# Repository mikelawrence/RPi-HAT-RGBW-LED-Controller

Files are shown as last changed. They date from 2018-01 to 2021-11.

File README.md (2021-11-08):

# Raspberry Pi RGBW LED Controller HAT
This is a [Raspberry Pi B+ HAT](https://github.com/raspberrypi/hats) that supports four high power LEDs. Each LED output uses a resistor configurable constant current driver with PWM support to control light intensity. A fourth LED channel was added to support color LEDs that have an extra Green or White LED. This HAT also supports Common-Anode LED configurations. The component selection as shown in the BOM is for a 50W RGB LED light that uses a constant current of 550mA at 24V-16.8V. The Design section discusses this in detail.

This PCB is designed using [KiCad 5.0.0](http://kicad.org). This HAT is based on [RPi_Hat_Template](https://github.com/xesscorp/RPi_Hat_Template) by XESS Corp.

_Note: The LM3414 parts have an exposed pad on the bottom which requires either a reflow oven or hot air to solder properly._

_Note: This HAT does not have the camera flex slot or the display flex cutout so technically cannot be called a HAT._

## Status
* Rev 1.0 PCB has been ordered, assembled, and tested.
  * Order the PCB from [OSH Park](https://oshpark.com/shared_projects/8nXTFx94).
  * Order the parts from Mouser using this [Shared BOM](https://www.mouser.com/ProjectManager/ProjectDetail.aspx?AccessID=8e67d22b4b).
  * The Green LED failed on one of my lights. The board is working as it should. This is most likely a LED module problem or incorrect output current. Replaced the module, changed the current from 550mA to 500mA and added a scale factor on the green output which currently limits the duty cycle to a maximum of 75%. Green output is higher in intensity anyways.

## Board Preview
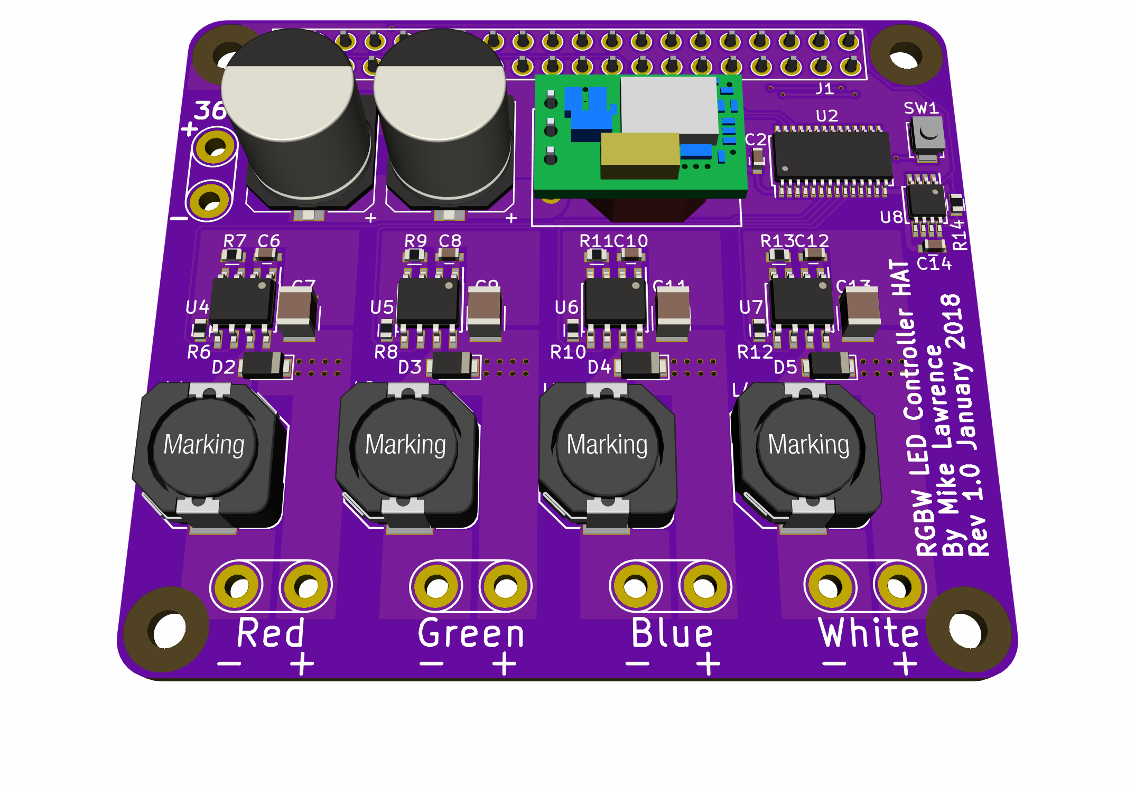
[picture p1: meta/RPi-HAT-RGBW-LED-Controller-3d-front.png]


## Design
### Input Power
Input power is 36VDC nominal with a range of 30V-37V. Input current is a maximum of 2A. This limit is due to the maximum current of the reverse input protection bridge rectifier (D1) which also serves to reduce the voltage on the 5V DC-DC converter (U3). If higher current is needed remove D1 and make the maximum input voltage 35VDC.

The Raspberry Pi can be safely back-powered by this HAT because the Ideal Diode circuit provides protection to both the Raspberry Pi and this HAT when the Raspberry Pi is powered by another source. Maximum Raspberry Pi power is 1.5A. Usually the Raspberry Pi will take substantially less than 1.5A when it is used with no external connections.

Example power budget...Powering a [50W RGB LED light](http://www.ebay.com/sch/sis.html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) purchased on eBay. The RGB LEDs of this light are wired with four wires in a common-anode configuration. For this light the White LED section is left unpopulated.

| | Current | Voltage | Power |
|---|---|---|---|
| Red | 550mA | 16.8V | 9.24W |
| Green | 550mA | 24V | 13.2W |
| Blue | 550mA | 24V | 13.2W |
| LED Power | | | 35.6W |
| LED Power @ 80% Efficiency| | | 44.6W |
| Raspberry Pi | | | 10.0W |
| Total System Power | | | 54.6W |

A 60W 36VDC power supply will drive the Raspberry Pi, RGBW LED Controller HAT, and the High Power LEDs. [This](http://www.meanwellusa.com/webapp/product/search.aspx?prod=HLG-60H) power supply (part number HLG-60) from Mean Well will drive the 50W RGB light nicely.

### Power Reality Check
In my testing I placed a Raspberry Pi, RGBW LED Controller HAT, and a 60W Power Supply in an enclosure to check temperatures. When I ran a rainbow sweep test the power consumption was around 18W and the HAT had a temperature rise of about 20C - 25C over room temperature. A static purple color test (both read and blue at full power) with power consumption around 35W the HAT temperature rise was 30C - 35C. Clearly this HAT will need better cooling to run higher power LED configurations.

### LED driver
The LM3414 from TI is a 1-A, 60-W Common Anode-Capable Constant Current Buck LED Driver. Most constant current LED drivers have a current sense resistor in the high-side path which prevents common anode connections. The LM3414 puts the current sense resistor on the low side. This leaves the high side connected directly to the 36V of the input power. The positive side of all four LED outputs are connected together on the board forcing a common-anode topology. You must not connect the low side to ground.

The LM3414 average LED current (I<sub>L</sub>) is set by the R<sub>IADJ</sub> (R7, R9, R11, R13). Set LED average current to 550mA using the equation below.

R_{IADJ}=\frac{3125}{I_{L}}=\frac{3125}{550\times10^{-3}}=5681\Omega \textup{ choose }5.76k\Omega\textup{ standard 1\% value}

Using the standard 1% resistor value the average LED current is

I_{L}=\frac{3125}{5.76\times10^{3}}=543mA}

Choose a standard switching frequency (f<sub>SW</sub>) of 500kHz using equation below. Switching frequency (f<sub>SW</sub>) is set by R<sub>FS</sub> (R6, R8, R10, R12).

R_{FS}=\frac{20\times10^9}{f_{SW}}=\frac{20\times10^9}{500\times10^3}=40k\Omega\textup{ choose }40.2k\Omega \textup{ standard 1\% value}

Using the standard 1% resistor value the switching frequency is

f_{SW}=\frac{20\times10^9}{R_{FS}}=\frac{20\times10^9}{40.2\times10^3}=498kHz

Determine minimum inductor value from maximum peak-to-peak LED current ripple (ΔI<sub>LPP</sub>) using equation below. Set ΔI<sub>LPP</sub> to 200mA.

L=\frac{(V_{IN}-V_{LED})\cdot V_{LED}}{f_{SW}\cdot V_{IN}\cdot \Delta I_{L-PP}}=\frac{(36-16.8)\cdot16.8}{498\times10^3\cdot 36\cdot 200\times10^3}=90\mu H\textup{ choose }100\mu H\textup{ standard value}

Using the standard inductor value the peak-to-peak LED current ripple is

\Delta I_{L-PP}=\frac{(V_{IN}-V_{LED})\cdot V_{LED}}{f_{SW}\cdot V_{IN}\cdot L}=\frac{(36-16.8)\cdot16.8}{498\times10^{3}\cdot 36\cdot 100\times10^{-6}}=180mA

Determine peak LED current (I<sub>LP</sub>) using selected components using equation below. I<sub>LP</sub> is also the peak current through the inductor.

I_{LP}=\frac{(V_{IN}-V_{LED})\cdot V_{LED}}{f_{SW}\cdot V_{IN}\cdot 2\cdot L}+I_{L}

I_{LP}=\frac{(36-16.8)\cdot16.8}{498\times10^{3}\cdot2\cdot 100\times10^{-6}}+543\times10^{-3}=633mA

Compute the operating duty cycle (D) using equation below.

D=\frac{V_{LED}}{V_{IN}}=\frac{16.8}{36}=0.467

Determine minimum C<sub>IN</sub> (C7, C9, C11, C13) for 200mV or less voltage ripple (ΔV<sub>IN</sub>) using equation below.

C_{IN}=\frac{D\cdot (1-D)\cdot I_{L}}{f_{SW}\cdot \Delta V_{IN}}

C_{IN}=\frac{0.467\cdot(1-0.467)\cdot 543\times10^{-3}}{498\times10^{3}\cdot200\times10^{-3}}=1.36\mu F\textup{ choose }2.2\mu F\textup{ standard value}

### PWM Controller
A Raspberry Pi has only one hardware capable PWM pin (GPIO18). With up to four PWM outputs needed for this HAT I decided to use a PCA9685 from NXP alleviate the load on the Raspberry Pi. The PCA9685 from NXP is a 16-Channel, 12-bit, I<sup>2</sup>C PWM controller. It supports independent LED on and off times so the LED outputs can be adjusted in phase along with pulse width. However, when phase is changed from 0 the next PWM cycle will reset the output. For frequent updates this causes the output light to flicker.

There are few settings that are important to using the PCA9685 on this HAT. First the EXTCLK bit in the MODE1 register must be set to 0. In the MODE2 register the INVRT bit must be set to 0 and the OUTDRV bit must be set to 1. Luckily this is the default state for all of these bits.

## Raspberry Pi Setup
This setup makes two key assumptions. First you are using Raspbian. Second, Python3 is the target programming environment. Install or update Python3 and necessary libraries by performing the following...
```
sudo apt-get update
sudo apt-get -y install build-essential python3-dev python3-pip git i2c-tools python3-w1thermsensor
pip3 install Adafruit-GPIO paho-mqtt
```

### Clone this Repository
Now is a good time to clone this repository on your Raspberry Pi. Clearly the KiCad files are not needed to configure and run this code on your Raspberry Pi so you pick and choose the files needed but these instructions will clone the entire repository.
```
mkdir ~/projects
cd ~/projects
git clone https://github.com/mikelawrence/RPi-HAT-RGBW-LED-Controller
```

### Configure ID EEPROM
Raspberry Pi HATs require an ID EEPROM with data that uniquely identifies every hat ever made. Start by cloning this repository on your Raspberry Pi, building the EEPROM tools, and make the the `eeprom_settings.eep` file.
```
cd ~/projects/RPi-HAT-RGBW-LED-Controller/eeprom/
make all
./eepmake eeprom_settings.txt eeprom_settings.eep
```
The next command writes the freshly generated and unique `eeprom_settings.eep` file to the EEPROM but you must push and hold the write switch on the HAT before executing this command. By default the EEPROM on the HAT is write protected. Pushing the write switch allows writes to occur.
```
sudo ./eepflash.sh -w -f=eeprom_settings.eep -t=24c32
```
You will see the following if writing to the EEPROM was successful.
```
This will attempt to talk to an eeprom at i2c address 0x50. Make sure there is an eeprom at this address.
This script comes with ABSOLUTELY no warranty. Continue only if you know what you are doing.
Do you wish to continue? (yes/no): yes
Writing...
0+1 records in
0+1 records out
117 bytes (117 B) copied, 2.31931 s, 0.1 kB/s
Done.
```
This is what you will see if there is a problem communicating with the EEPROM.
```
This will attempt to talk to an eeprom at i2c address 0x50. Make sure there is an eeprom at this address.
This script comes with ABSOLUTELY no warranty. Continue only if you know what you are doing.
Do you wish to continue? (yes/no): yes
Writing...
dd: error writing ‘/sys/class/i2c-adapter/i2c-3/3-0050/eeprom’: Connection timed out
0+1 records in
0+0 records out
0 bytes (0 B) copied, 0.0539977 s, 0.0 kB/s
Error doing I/O operation.
```

### Setup Interfaces
For this HAT you will need to enable the I<sup>2</sup>C and 1-Wire interfaces. From the command line type `sudo raspi-config ` and follow the prompts to install I<sup>2</sup>C support in the kernel.

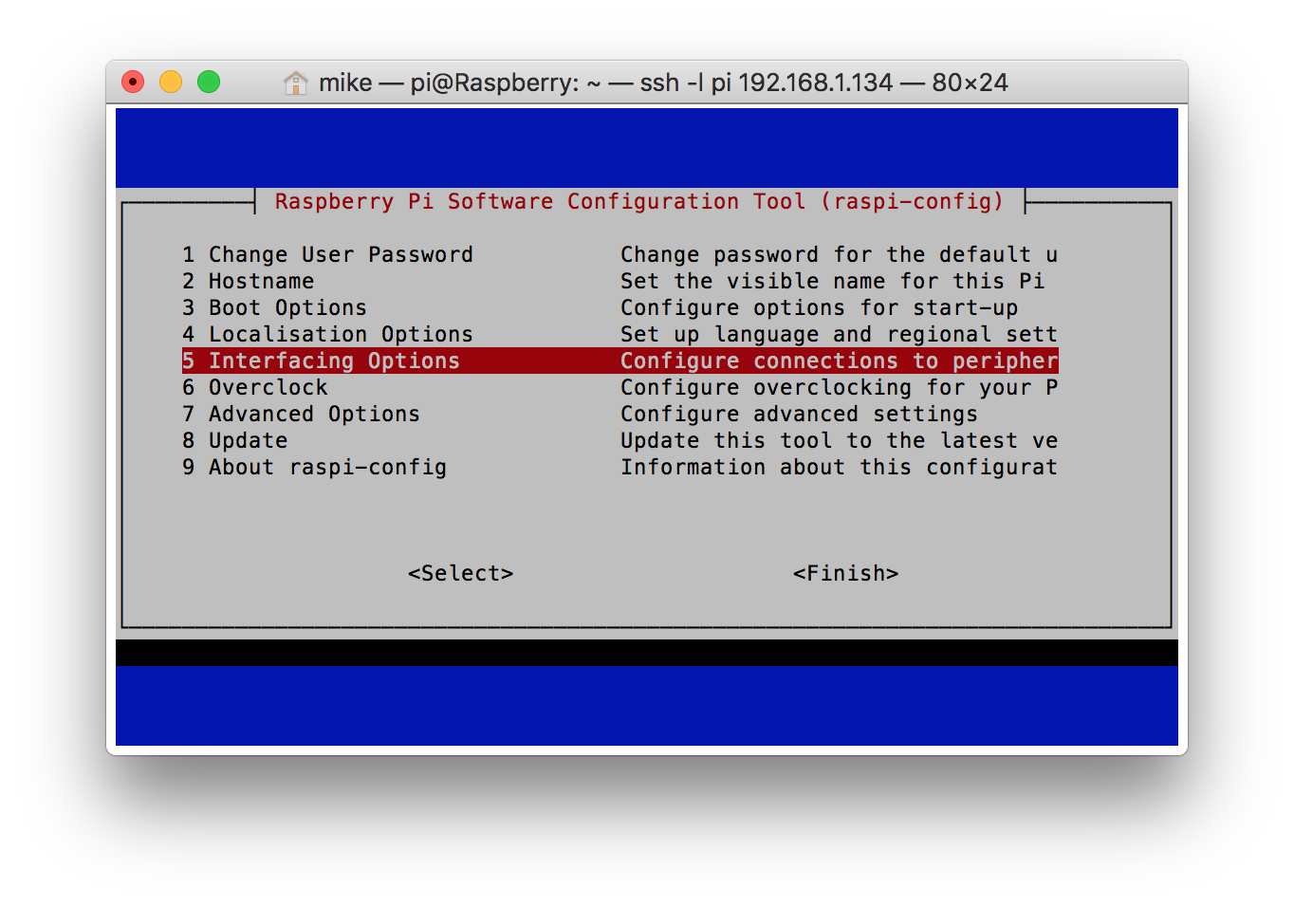
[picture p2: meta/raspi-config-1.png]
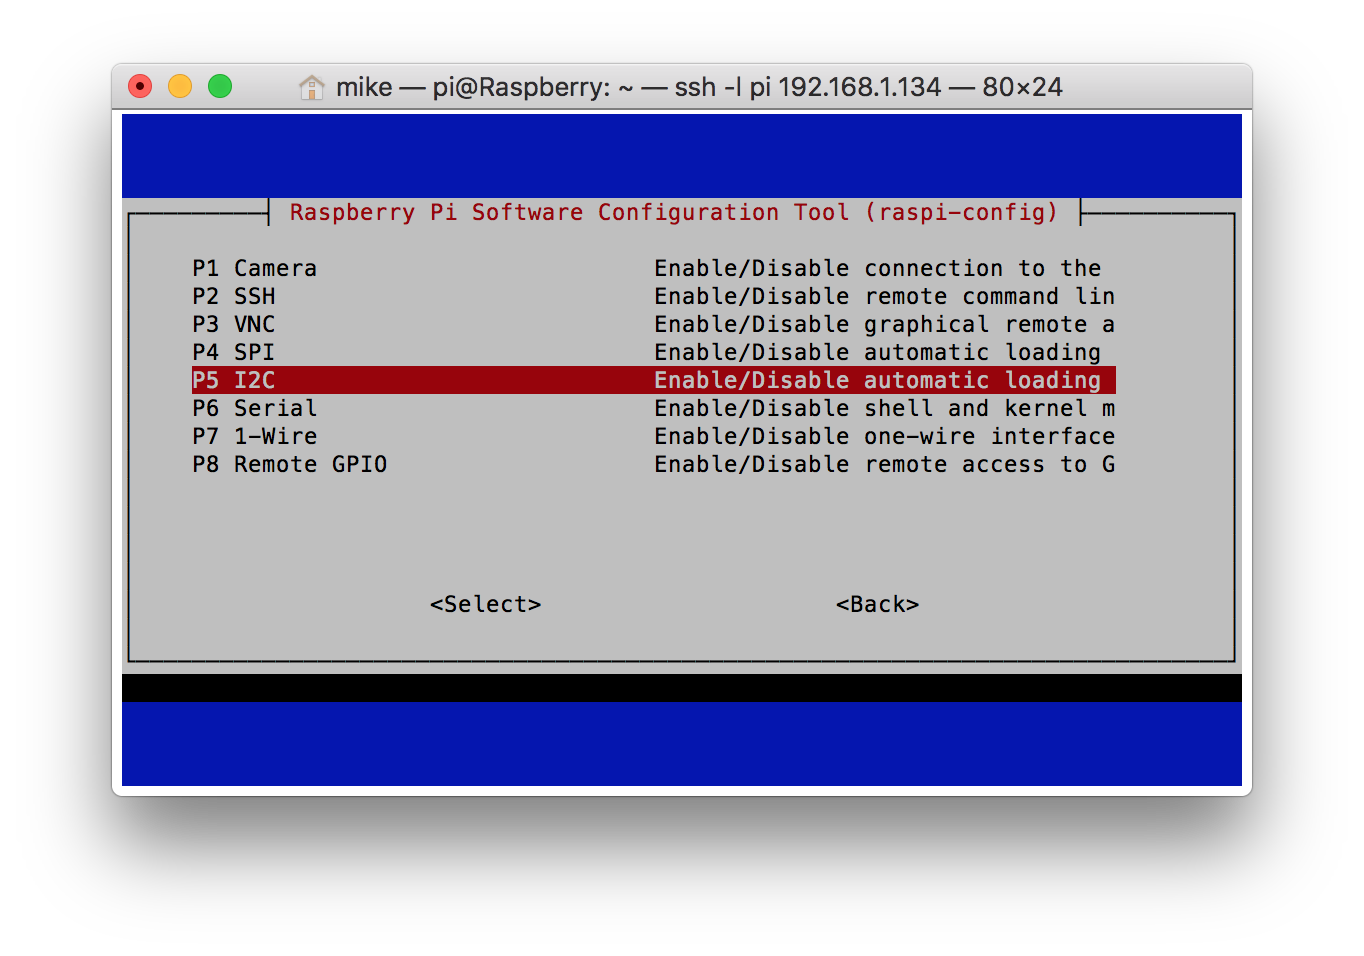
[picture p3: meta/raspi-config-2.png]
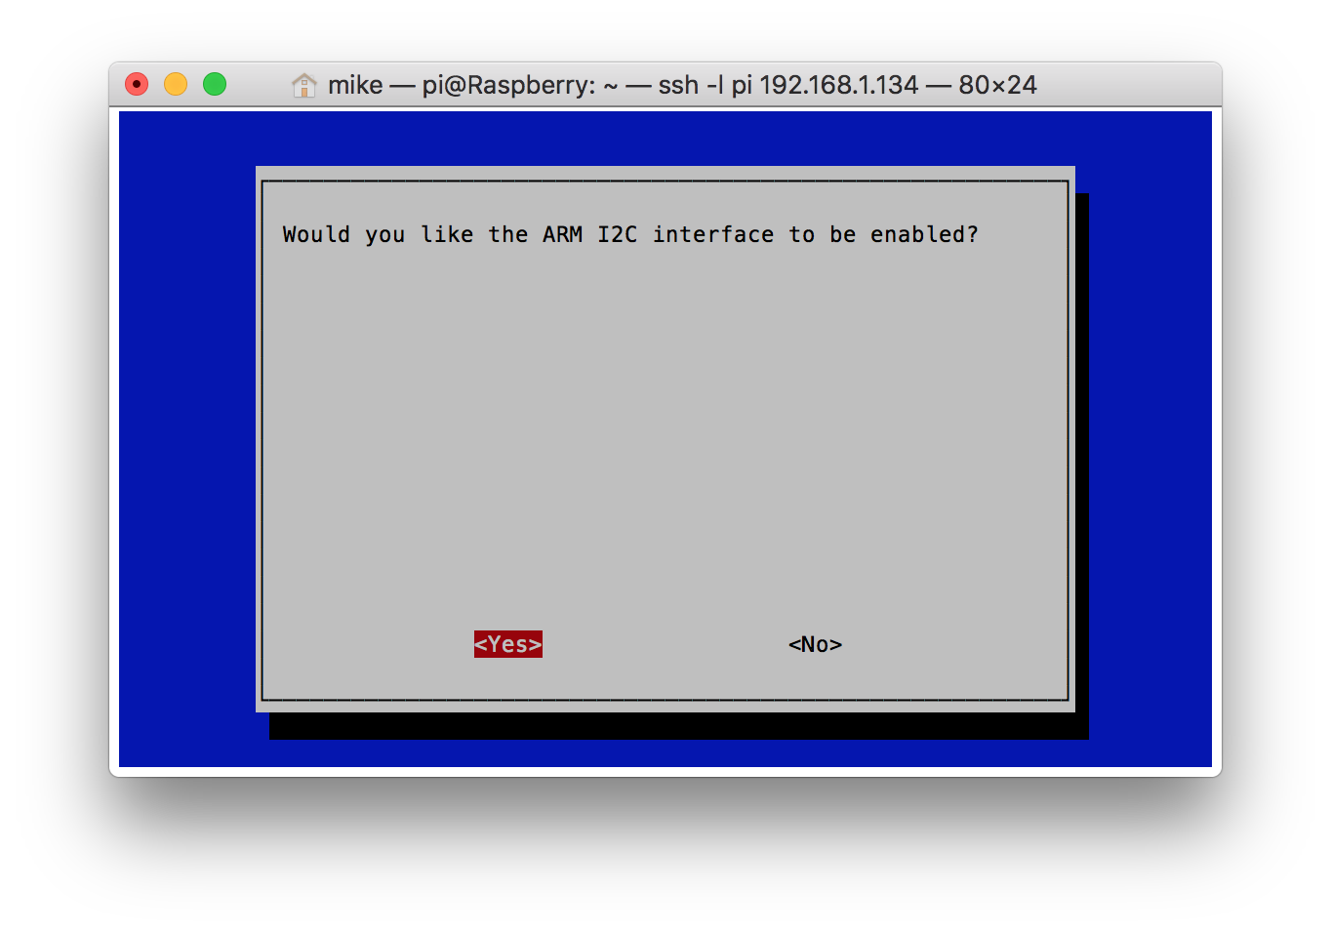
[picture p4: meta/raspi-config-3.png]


Now follow the same actions but enabling the 1-Wire interface.

It's time to reboot your Raspberry Pi with `sudo reboot`.

### Test PCA9685 12-bit PWM Controller
Now let's see if the PWM Controller is present on the I<sup>2</sup>C bus by running `sudo i2cdetect -y 1`. Looking at the output of the `i2cdetect` command you will see `40` and `70` in a field of `--` when the PCA9685 is detected on the bus. If you don't see the `40` something is wrong with the HAT or the bus is disabled. `i2cdetect` was installed when you installed the i2c-tools package in the Raspberry Pi Setup section.
```
pi@rpi-rgb-led-1:~ $ sudo i2cdetect -y 1
     0  1  2  3  4  5  6  7  8  9  a  b  c  d  e  f
00:          -- -- -- -- -- -- -- -- -- -- -- -- --
10: -- -- -- -- -- -- -- -- -- -- -- -- -- -- -- --
20: -- -- -- -- -- -- -- -- -- -- -- -- -- -- -- --
30: -- -- -- -- -- -- -- -- -- -- -- -- -- -- -- --
40: 40 -- -- -- -- -- -- -- -- -- -- -- -- -- -- --
50: -- -- -- -- -- -- -- -- -- -- -- -- -- -- -- --
60: -- -- -- -- -- -- -- -- -- -- -- -- -- -- -- --
70: 70 -- -- -- -- -- -- --                         
```

### Test the DS18B20 1-Wire Thermometer
[Python3-w1thermsensor](https://github.com/timofurrer/w1thermsensor) is a nice 1-Wire python library that also supports command line reading of temperatures from 1-Wire devices. You should have already installed this package in the [Raspberry Pi Setup](#Raspberry-Pi-Setup) section.

Now test the RGBW LED Controller HAT's DS18B20 temperature sensor using `w1thermsensor all`.
```
pi@rpi-rgb-led-1:~ $ w1thermsensor all
Got temperatures of 1 sensors:
  Sensor 1 (00000991f822) measured temperature: 25.69 celsius
```
# RGBW LED Controller HAT Test
See code-test section [README.md](code-test/README.md) for code that fires up the RGBW LED Controller HAT by blending between the primary colors and monitoring temperatures.

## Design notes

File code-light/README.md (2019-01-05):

# RGB Floodlight Application
The RGB Floodlight application is written in Python 3 and supports the RGB hardware elements of the RGBW LED Controller HAT which in turn drives a 50W RGB Floodlight. The application is also a discoverable light for [Home Assistant](https://home-assistant.io/), an open-source home automation platform running on Python 3. [MQTT](http://mqtt.org/), a machine-to-machine (M2M)/"Internet of Things" connectivity protocol, is the basis of communication with Home Assistant.

All settings for this application are in the '[rgbfloodlight.conf](rgbfloodlight.conf)'. This is where you point to the correct MQTT broker and configure how the light works. There are a few settings of note here. Discovery_Enabled = false will prevent Home Assistant from automatically discovering the light. Group_Enable = true adds a second MQTT light to Home Assistant that supports multiple RGB Floodlights. Each light that has the same Group_ID will respond state changes in unison. Be sure to set Group_Master = true for only one light in a group.

If you don't want to use discovery here is the configuration of the light in Home Assistant. Note the 'Studio-Roof-Floodlight' you see in the example yaml is the Node_ID which is specified in the 'rgbfloodlight.conf' file. The light platform for Home Assistant is [MQTT JSON Light](https://www.home-assistant.io/components/light.mqtt//) configured with RGB and brightness support. The RGB Floodlight also reports internal temperature (platform [MQTT Sensor](https://home-assistant.io/components/sensor.mqtt/)) and an over temperature alarm (platform [MQTT Binary_Sensor](https://home-assistant.io/components/binary_sensor.mqtt/))
```yaml
# Example configuration.yaml entry
light:
  # Main RGB Light config
  - platform: mqtt_json
    name: Studio Roof Light
    state_topic: "hass/light/studio_roof_light/rgblight/state"
    command_topic: "hass/light/studio_roof_light/rgblight/set"
    brightness: true
    rgb: true
    effect: true
    qos: 1
    retain: true
    brightness_scale: 255
    effect_list:
      - Single Color
      - Single Color Bounce
      - Primary Bounce
      - Primary Blend
      - Rainbow Bounce
      - Rainbow Blend
      - Christmas
      - Halloween
# Include the next three settings if you want availability in Home Assistant
# Availability seems marginal in Home Assistant and frequently disables
# light controls even when the light is operational.
    availability_topic: "hass/light/studio_roof_light/rgblight/status"
    payload_available: "online"
    payload_not_available: "offline"

  # Group RGB Lights config
  - platform: mqtt_json
    name: Roof Lights
    state_topic: "hass/light/roof_lights/rgblight/state"
    command_topic: "hass/light/roof_lights/rgblight/set"
    brightness: true
    rgb: true
    effect: true
    qos: 1
    retain: true
    brightness_scale: 255
    effect_list:
      - Single Color
      - Single Color Bounce
      - Primary Bounce
      - Primary Blend
      - Rainbow Bounce
      - Rainbow Blend
      - Christmas
      - Halloween

sensor:
  - platform: mqtt
    name: Studio Roof Light RSSI
    state_topic: "hass/sensor/studio_roof_light/rssi/state"
    unit_of_measurement: "dBm"
  - platform: mqtt
    name: Studio Roof Light Temperature
    state_topic: "hass/sensor/studio_roof_light/temperature/state"
    unit_of_measurement: "°C"

binary_sensor:
  - platform: mqtt
    name: Studio Roof Light Over Temperature Alarm
    state_topic: "hass/binary_sensor/studio_roof_light/hat_temperature/state"
    device_class: "heat"
    payload_on: "ON"
    payload_off: "OFF"
```
The RGB Light subscribes to the command_topic and expects JSON control data in the following format...

```JSON
{
  "brightness": 255,
  "color": {
    "r": 255,
    "g": 255,
    "b": 255
  },
  "effect": "Single Color",
  "state": "ON",
  "transition": 120
}
```
Note the "transition" parameter specifies how long a given effect last before repeating and is not part of the Home Assistant light control so an additional control and automation is required see below..
```yaml
# Input slider for transition time
input_number:
  studio_roof_light_transition_time:
    name: "Studio Roof Light Transition Speed"
    initial: 120
    min: 1
    max: 180
    step: 1

# automation to pipe the transition value over to light
automation:
  - id: studio_roof_light_transition_speed
    alias: "Studio Roof Light Transition Speed"
    initial_state: True
    hide_entity: False
    trigger:
      - platform: state
        entity_id: input_number.studio_roof_light_transition_time
    action:
      - service: mqtt.publish
        data_template:
          topic: "hass/light/studio_roof_light/rgblight/set"
          payload: '{"transition": {{ trigger.to_state.state | int }}}'

```
## Other Software Notes
The PCA9685 driver is based on Adafruit's Python PCA9685 library (PCA9685.py). While this library works it had some problems. First every register write is a single 8-bit I<sup>2</sup>C transaction even for those registers like LEDn_ON which are actually two 8-bit registers together. So I changed all multi-register writes to support the writeList() method which writes multiple bytes from a starting address in a single transaction. This required also setting the AI bit in the MODE1 register which configures the PCA9685 to auto-increment the address counter on I<sup>2</sup>C transactions. Finally I added a method, set_multiple_pwm(), that writes the LED On and LED Off values for multiple PWM channels starting with CH0. This allows the RGB PWM values to be updated simultaneously.

The rgbled.py file provides all of the RGB LED control through the PCA9685 PWM controller. Once initialized use the set() method to change color and brightness which in turn will compute appropriate PWM values and send them to the PCA9685.

The Color class is defined in the color.py file. Color is defined as a tuple representing a color using Red, Green, and Blue values with a range of [0:255]. This class defines the blend() method used to linearly blend from one color to the next. Gamma correction is provided by the gamma() method.

The colorwheel.py file is a set of classes that provide a convenient method of converting an angle with the range [0:360] to a color that is either a blend between multiple colors or a bounce effect of fading out one color before switching to another. Multiple colorwheel classes are defined as effects. For instance there is the PrimaryBlendWheel which blends between the primary colors. Or the RainbowBounceWheel which fades between colors of the Rainbow.

## Raspberry Pi Setup
This setup makes two key assumptions. First you are using Raspbian. Second, Python 3 is the target programming environment. It is assumed that you already installed the required tools and libraries as shown in the main project [README file](../README.md) but here are the commands to install or update Python 3 and necessary libraries...
```
sudo apt-get update
sudo apt-get -y install build-essential python3-dev python3-pip git i2c-tools python3-w1thermsensor
pip3 install Adafruit-GPIO paho-mqtt
```
It is also assumed that you already cloned this repository as shown in the Clone This Repository section of the main project [README file](../README.md). Be sure to edit the 'rgbfloodlight.conf' file to support your configuration. Test the software by executing the following commands.
```
cd ~/projects/RPi-HAT-RGBW-LED-Controller/code-light/
chmod 755 rgbfloodlight.py
./rgbfloodlight.py
```
If you see no errors you should be able to see your light in Home Assistant. Configuring Home Assistant is a bit of a stretch for this guide but here are a couple of hints.

* "RGB Floodlight: Failed to load state file 'rgbfloodlightstate.json'." means there is no previous state for the light. This is perfectly normal when the code is run for the first time.
* Make sure you have MQTT installed. If you use HASS.IO goto the HASS.IO configuration and install the Mosquitto Broker.
* Make sure you have MQTT discovery enabled. See [MQTT Discovery](https://home-assistant.io/docs/mqtt/discovery/).
* Make sure your MQTT discovery prefix matches the Discovery_Prefix in your RGB Floodlight configuration file.

I use HASS.IO with the Mosquitto Broker add-on installed and my configuration for MQTT is as follows...
```yaml
mqtt:
  broker: core-mosquitto
  discovery: true
  discovery_prefix: hass

```
## Systemd run at boot
To make this code run at boot enter the following commands...
```
cd ~/projects/RPi-HAT-RGBW-LED-Controller/code-light
sudo cp rgbfloodlight.service /lib/systemd/system
sudo systemctl enable rgbfloodlight.service
sudo systemctl start rgbfloodlight.service
```

# Acknowledgments
The following python libraries are required.
* [Eclipse Paho™ MQTT Python Client](https://github.com/eclipse/paho.mqtt.python)
* [Python3 w1thermsensor](https://github.com/timofurrer/w1thermsensor)
* [Adafruit Python GPIO](https://github.com/adafruit/Adafruit_Python_GPIO)

The following library is used but was modified so included in this repository.
* [Adafruit Python PCA9685](https://github.com/adafruit/Adafruit_Python_PCA9685).

The following code was pulled from the Internet
* [kbhit.py](http://home.wlu.edu/~levys/software/kbhit.py) from Simon D. Levy
* [timer.py](https://github.com/jalmeroth/homie-python/blob/master/homie/timer.py)

I want to thank Jan Almeroth for [homie-python](https://github.com/jalmeroth/homie-python/blob/master/homie/timer.py) which is a Python implementation of the Homie MQTT convention. While I ended up not using Homie it showed me how to use the Paho MQTT Python Client.

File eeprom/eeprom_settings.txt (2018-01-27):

########################################################################
# EEPROM settings text file
#
# This text file has been modifed for the Raspberry Pi Thermocouple Hat.
#
# Edit this file for your particular board and run through eepmake tool,
# then use eepflash tool to write to attached HAT ID EEPROM
#
# Tools available:
#  eepmake   Parses EEPROM text file and creates binary .eep file
#  eepdump   Dumps a binary .eep file as human readable text (for debug)
#  eepflash  Write or read .eep binary image to/from HAT EEPROM
#
########################################################################

########################################################################
# Vendor info

# 128 bit UUID. If left at zero eepmake tool will auto-generate
# RFC 4122 compliant UUID
product_uuid 00000000-0000-0000-0000-000000000000

# 16 bit product id
product_id 0x0003

# 16 bit product version
product_ver 0x0000

# ASCII vendor string  (max 255 characters)
vendor "Mike Lawrence"

# ASCII product string (max 255 characters)
product "RGBW LED Controller Hat"

########################################################################
# GPIO bank settings, set to nonzero to change from the default.
# NOTE these setting can only be set per BANK, uncommenting any of
# these will force the bank to use the custom setting.

# drive strength, 0=default, 1-8=2,4,6,8,10,12,14,16mA, 9-15=reserved
gpio_drive 0

# 0=default, 1=slew rate limiting, 2=no slew limiting, 3=reserved
gpio_slew 0

# 0=default, 1=hysteresis disabled, 2=hysteresis enabled, 3=reserved
gpio_hysteresis 0

# If board back-powers Pi via 5V GPIO header pins:
# 0 = board does not back-power
# 1 = board back-powers and can supply the Pi with a minimum of 1.3A
# 2 = board back-powers and can supply the Pi with a minimum of 2A
# 3 = reserved
# If back_power=2 then USB high current mode will be automatically
# enabled on the Pi
back_power 1

########################################################################
# GPIO pins, uncomment for GPIOs used on board
# Options for FUNCTION: INPUT, OUTPUT, ALT0-ALT5
# Options for PULL: DEFAULT, UP, DOWN, NONE
# NB GPIO0 and GPIO1 are reserved for ID EEPROM so cannot be set

#         GPIO  FUNCTION  PULL
#         ----  --------  ----
setgpio   2     ALT0      DEFAULT    # I2C
setgpio   3     ALT0      DEFAULT    # I2C
#setgpio  4     INPUT     DEFAULT
#setgpio  5     OUTPUT    DOWN
#setgpio  6     INPUT     DEFAULT
#setgpio  7     INPUT     DEFAULT
#setgpio  8     INPUT     DEFAULT
#setgpio  9     INPUT     DEFAULT
#setgpio  10    INPUT     DEFAULT
#setgpio  11    INPUT     DEFAULT
#setgpio  12    INPUT     DEFAULT
#setgpio  13    INPUT     DEFAULT
#setgpio  14    INPUT     DEFAULT
#setgpio  15    INPUT     DEFAULT
#setgpio  16    INPUT     DEFAULT
#setgpio  17    INPUT     DEFAULT
#setgpio  18    INPUT     DEFAULT
#setgpio  19    INPUT     DEFAULT
#setgpio  20    INPUT     DEFAULT
#setgpio  21    INPUT     DEFAULT
#setgpio  22    INPUT     DEFAULT
#setgpio  23    INPUT     DEFAULT
#setgpio  24    INPUT     DEFAULT
#setgpio  25    INPUT     DEFAULT
#setgpio  26    INPUT     DEFAULT
#setgpio  27    INPUT     DEFAULT

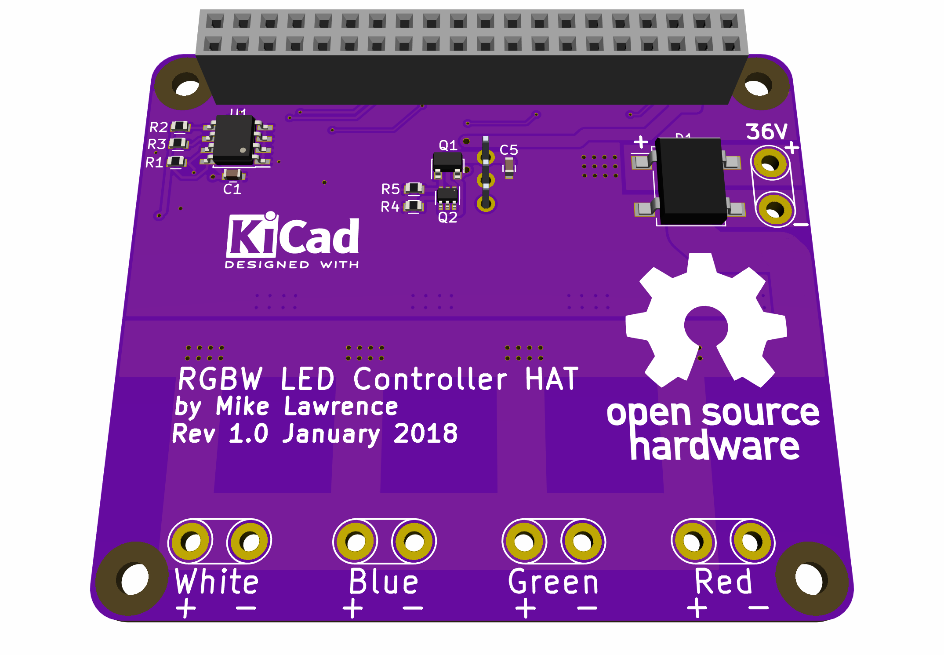
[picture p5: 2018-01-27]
meta/RPi-HAT-RGBW-LED-Controller-3d-back.png

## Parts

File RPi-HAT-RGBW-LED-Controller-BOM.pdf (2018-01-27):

# RPi RGBW LED Controller HAT Rev 1.0

Reference | Quantity | Value | Part Number | Manufacturer | Vendor | Vendor Part Number | Tolerance | Voltage
C1 C2 C14 | 3 | 0.1uF | GCJ188R71E104KA2D | Murata | Mouser | 81-GCJ188R71E104KA2D | 10% | 25V
C3 C4 | 2 | 330uF | EEE-FT1H331GP | Panasonic | Mouser | 667-EEE-FT1H331GP | 20% | 50V
C5 C6 C8 C10 C12 | 5 | 1uF | GCJ188R71E105KA01D | Murata | Mouser | 81-GCJ188R71E105KA1D | 10% | 25V
C7 C9 C11 C13 | 4 | 2.2uF | GCJ32DR72A225KA01L | Murata | Mouser | 81-GCJ32DR72A225KA1L | 10% | 100V
D1 | 1 | | DF206ST-G | Comchip Tech | Mouser | 750-DF206ST-G
D2 D3 D4 D5 | 4 | | DFLS2100-7 | Diodes Inc | Mouser | 621-DFLS2100-7
J1 | 1 | | 2222 | Adafruit | Mouser | 485-2222
L1 L2 L3 L4 | 4 | 100uH | 7447714101 | Wurth | Mouser | 710-7447714101
Q1 | 1 | | DMG2305UX-7 | Diodes Inc | Mouser | 621-DMG2305UX-7
Q2 | 1 | | BCM857BS-7-F | Diodes Inc | Mouser | 621-BCM857BS-7-F
R1 | 1 | 1k | ERJ-3EKF1001V | Panasonic | Mouser | 667-ERJ-3EKF1001V | 1%
R14 | 1 | 4.7k | ERJ-3EKF4701V | Panasonic | Mouser | 667-ERJ-3EKF4701V | 1%
R2 R3 | 2 | 3.9k | ERJ-3EKF3901V | Panasonic | Mouser | 667-ERJ-3EKF3901V | 1%
R4 | 1 | 10k | ERJ-3EKF1002V | Panasonic | Mouser | 667-ERJ-3EKF1002V | 1%
R5 | 1 | 47k | ERJ-3EKF4702V | Panasonic | Mouser | 667-ERJ-3EKF4702V | 1%
R6 R8 R10 R12 | 4 | 40.2k | ERJ-3EKF4022V | Panasonic | Mouser | 667-ERJ-3EKF4022V | 1%
R7 R9 R11 R13 | 4 | 5.76k | ERJ-3EKF5761V | Panasonic | Mouser | 667-ERJ-3EKF5761V | 1%
SW1 | 1 | | B3U-1000P | Omron | Mouser | 653-B3U-1000P
U1 | 1 | | AT24CS32-SSHM | Atmel | Mouser | 556-AT24CS32-SSHM-T
U2 | 1 | | PCA9685PW | NXP | Mouser | 771-PCA9685PW,112
U3 | 1 | | OKI-78SR-5/1.5-W36H-C | Murata | Mouser | 580-OKI78SR51.5W36HC
U4 U5 U6 U7 | 4 | | LM3414MRX/NOPB | TI | Mouser | 926-LM3414MRX/NOPB
U8 | 1 | | DS18B20U+ | Maxim | Mouser | 700-DS18B20U

1

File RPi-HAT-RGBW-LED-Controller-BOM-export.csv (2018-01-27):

Reference | Quantity | Value | Footprint | Datasheet | Part Number | Manufacturer | Vendor | Vendor Part Number | Tolerance | Voltage
C1 C14 C2 | 3 | 0.1uF | Capacitors_SMD:C_0603 |  | GCJ188R71E104KA2D | Murata | Mouser | 81-GCJ188R71E104KA2D | 10% | 25V
C3 C4 | 2 | 330uF | Capacitors_SMD:CP_Elec_10x10.5 |  | EEE-FT1H331GP | Panasonic | Mouser | 667-EEE-FT1H331GP | 20% | 50V
C10 C12 C5 C6 C8 | 5 | 1uF | Capacitors_SMD:C_0603 |  | GCJ188R71E105KA01D | Murata | Mouser | 81-GCJ188R71E105KA1D | 10% | 25V
C11 C13 C7 C9 | 4 | 2.2uF | Capacitors_SMD:C_1210 |  | GCJ32DR72A225KA01L | Murata | Mouser | 81-GCJ32DR72A225KA1L | 10% | 100V
D1 | 1 | D_Bridge_+-AA | Diodes_SMD:Diode_Bridge_DFS | https://www.mouser.com/ds/2/80/DF2005S-G%20Thru340567.%20DF210S-G%20RevF-535444.pdf | DF206ST-G | Comchip Tech | Mouser | 750-DF206ST-G
D2 D3 D4 D5 | 4 | DFLS2100 | Diodes_SMD:D_PowerDI-123 | https://www.diodes.com/assets/Datasheets/ds31475.pdf | DFLS2100-7 | Diodes Inc | Mouser | 621-DFLS2100-7
J1 | 1 | RPi_GPIO | raspberry-ml:Pin_Header_Straight_2x20 |  | 2222 | Adafruit | Mouser | 485-2222
J2 J3 J4 J5 J6 | 5 | Conn_01x02_Female | holes-ml:TH_16ga_2pos
L1 L2 L3 L4 | 4 | 100uH | inductors-ml:WE-PD-1050 |  | 7447714101 | Wurth | Mouser | 710-7447714101
Q1 | 1 | DMG2305UX | TO_SOT_Packages_SMD:SOT-23 | https://www.diodes.com/assets/Datasheets/DMG2305UX.pdf | DMG2305UX-7 | Diodes Inc | Mouser | 621-DMG2305UX-7
Q2 | 1 | BCM857BS | TO_SOT_Packages_SMD:SOT-363_SC-70-6 | https://www.diodes.com/assets/Datasheets/BCM857BS.pdf | BCM857BS-7-F | Diodes Inc | Mouser | 621-BCM857BS-7-F
R1 | 1 | 1k | Resistors_SMD:R_0603 |  | ERJ-3EKF1001V | Panasonic | Mouser | 667-ERJ-3EKF1001V | 1%
R14 | 1 | 4.7k | Resistors_SMD:R_0603 |  | ERJ-3EKF4701V | Panasonic | Mouser | 667-ERJ-3EKF4701V | 1%
R2 R3 | 2 | 3.9k | Resistors_SMD:R_0603 |  | ERJ-3EKF3901V | Panasonic | Mouser | 667-ERJ-3EKF3901V | 1%
R4 | 1 | 10k | Resistors_SMD:R_0603 |  | ERJ-3EKF1002V | Panasonic | Mouser | 667-ERJ-3EKF1002V | 1%
R5 | 1 | 47k | Resistors_SMD:R_0603 |  | ERJ-3EKF4702V | Panasonic | Mouser | 667-ERJ-3EKF4702V | 1%
R10 R12 R6 R8 | 4 | 40.2k | Resistors_SMD:R_0603 |  | ERJ-3EKF4022V | Panasonic | Mouser | 667-ERJ-3EKF4022V | 1%
R11 R13 R7 R9 | 4 | 5.76k | Resistors_SMD:R_0603 |  | ERJ-3EKF5761V | Panasonic | Mouser | 667-ERJ-3EKF5761V | 1%
SW1 | 1 | Write | Buttons_Switches_SMD:SW_SPST_B3U-1000P | http://www.mouser.com/ds/2/307/en-b3u-3615.pdf | B3U-1000P | Omron | Mouser | 653-B3U-1000P
U1 | 1 | AT24CS32 | Housings_SOIC:SOIC-8_3.9x4.9mm_Pitch1.27mm | http://www.atmel.com/images/Atmel-8869-SEEPROM-AT24CS32-Datasheet.pdf | AT24CS32-SSHM | Atmel | Mouser | 556-AT24CS32-SSHM-T
U2 | 1 | PCA9685 | Housings_SSOP:TSSOP-28_4.4x9.7mm_Pitch0.65mm |  | PCA9685PW | NXP | Mouser | 771-PCA9685PW,112
U3 | 1 | OKI-78SR-5 | murata-ml:78SR-H |  | OKI-78SR-5/1.5-W36H-C | Murata | Mouser | 580-OKI78SR51.5W36HC
U4 U5 U6 U7 | 4 | LM3414 | Housings_SOIC:TI_SO-PowerPAD-8_ThermalVias |  | LM3414MRX/NOPB | TI | Mouser | 926-LM3414MRX/NOPB
U8 | 1 | DS18B20U | Housings_SSOP:MSOP-8_3x3mm_Pitch0.65mm | https://datasheets.maximintegrated.com/en/ds/DS18B20.pdf | DS18B20U+ | Maxim | Mouser | 700-DS18B20U

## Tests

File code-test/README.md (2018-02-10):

# RGBW LED Controller HAT Test Software
The test software is written in Python 3 and supports all hardware elements on the RGBW LED Controller HAT.

The PCA9685 driver is based on Adafruit's Python PCA9685 library (PCA9685.py). While this library works it had some problems. First every register write is a single 8-bit I<sup>2</sup>C transaction even for those registers like LEDn_ON which are actually two 8-bit registers together. So I changed all multi-register writes to support the writeList function which writes multiple bytes from a starting address in a single transaction. This required also setting the AI bit in the MODE1 register which configures the PCA9685 to auto-increment the address counter. Finally I added a function that writes the LED On and LED Off values for multiple PWM channels starting with CH0. This allows the RGB PWM values to be updated simultaneously.

The rgbled.py file provides most of the color processing and RGB LED control through the PCA9685 PWM controller. Color is defined as a tuple representing a color using Red, Green, and Blue values with a range of [0:255]. The LinearWheel and SineWheel classes provide a convenient HSV to RGB color converter that takes a Hue angle with the range [0:360] and converts it to a color. The Linear Wheel uses a linear translation of colors while the SineWheel uses a Sine wave translation of colors. This [website](http://www.instructables.com/id/How-to-Make-Proper-Rainbow-and-Random-Colors-With-/) has a good explanation of the difference between linear and sinusoid hue translations.

## Example
Running test.py will start rotating through the colors of the rainbow and periodically checking the CPU and HAT temperatures.

First make sure make the python file is executable by executing the following commands.
```
cd ~/projects/RPi-HAT-RGBW-LED-Controller/code-test
chmod 755 test.py
./test.py
```
You should see something similar to the output below and more interesting your LED light should cycling through the colors of the rainbow.
```
pi@rpi-rgb-led-1:~/projects/RPi-HAT-RGBW-LED-Controller/code-test $
RPi RGBW LED Controller HAT Test
Found 1-Wire temp sensor 00000991f822

Press any key to exit.
CPU Temp = 47.2C, HAT Temp 35.4C
CPU Temp = 47.2C, HAT Temp 35.6C
CPU Temp = 47.2C, HAT Temp 35.7C
CPU Temp = 47.2C, HAT Temp 35.8C
CPU Temp = 47.8C, HAT Temp 35.9C
```

# Acknowledgments
The following python libraries were used to demonstrate the functionality of the Raspberry Pi RGBW LED Controller HAT.
* [Python3 w1thermsensor](https://github.com/timofurrer/w1thermsensor)
* [Adafruit Python GPIO](https://github.com/adafruit/Adafruit_Python_GPIO)

The following libraries were used but had to be modified.
* [Adafruit Python PCA9685](https://github.com/adafruit/Adafruit_Python_PCA9685).

The following code was pulled from the Internet
* [kbhit.py](http://home.wlu.edu/~levys/software/kbhit.py) from Simon D. Levy
* [timer.py](https://stackoverflow.com/questions/12435211/python-threading-timer-repeat-function-every-n-seconds)

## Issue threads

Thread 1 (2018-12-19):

LM3414 Symbol

blasslett, 2018-12-19:
I noticed your LM3414 symbol pins do not match what is on the datasheet.  I'm new to kicad and wanted to make sure I wasn't missing something when creating my symbol since I'm using your design as a reference.

[http://www.ti.com/ds_dgm/images/alt_snvs678f.gif](url)

mikelawrence, 2018-12-19:
My symbol pin names and numbers match what is in the datasheet but the pin locations on the schematic symbol do not match the schematic symbol you presented. I swapped pin 3 and 6 on the symbol to make my schematic less confusing. Specifically I didn't like the PWM input on the right side of this symbol. Changes like this are a matter of personal preference. Just so you know this design has been built and is in use.

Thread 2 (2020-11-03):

Not able to open in Kicad, error loading board file "(" in input/source, it also states line 6, offset 1

stefanm666, 2020-11-03:
Not able to open in Kicad, error loading board file "(" in input/source, it also states line 6, offset 1.

I wanted to modify this to suit the HV version of the LM3414, remove the power source for the PCA9685 and Rpi to run higher input voltage and make it 8 channels.

Closed 2020-11-03.

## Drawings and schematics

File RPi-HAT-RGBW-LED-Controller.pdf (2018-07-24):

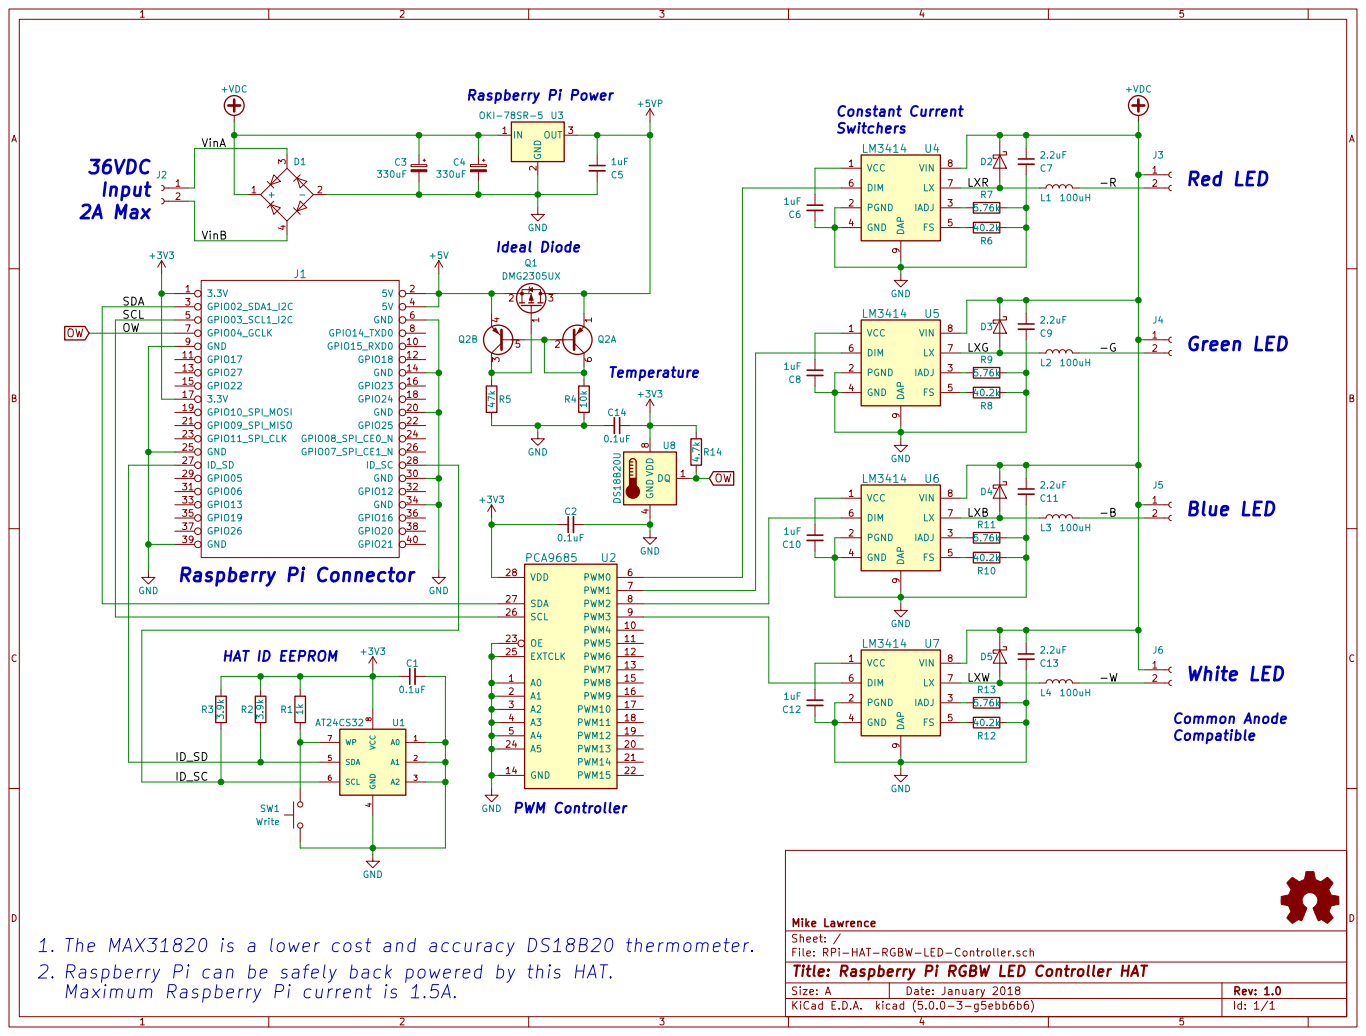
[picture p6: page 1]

Raspberry Pi Power GND

SW1 Write HAT ID EEPROM

4 SDA 5 SCL 6 WP 7 VCC

1. The MAX31820 is a lower cost and accuracy DS18B20 thermometer.
Raspberry Pi can be safely back powered by this HAT.
Maximum Raspberry Pi current is 1.5A.

File: RPi-HAT-RGBW-LED-Controller.sch Sheet: / Mike Lawrence

Id: 1/1 Title: Raspberry Pi RGBW LED Controller HAT

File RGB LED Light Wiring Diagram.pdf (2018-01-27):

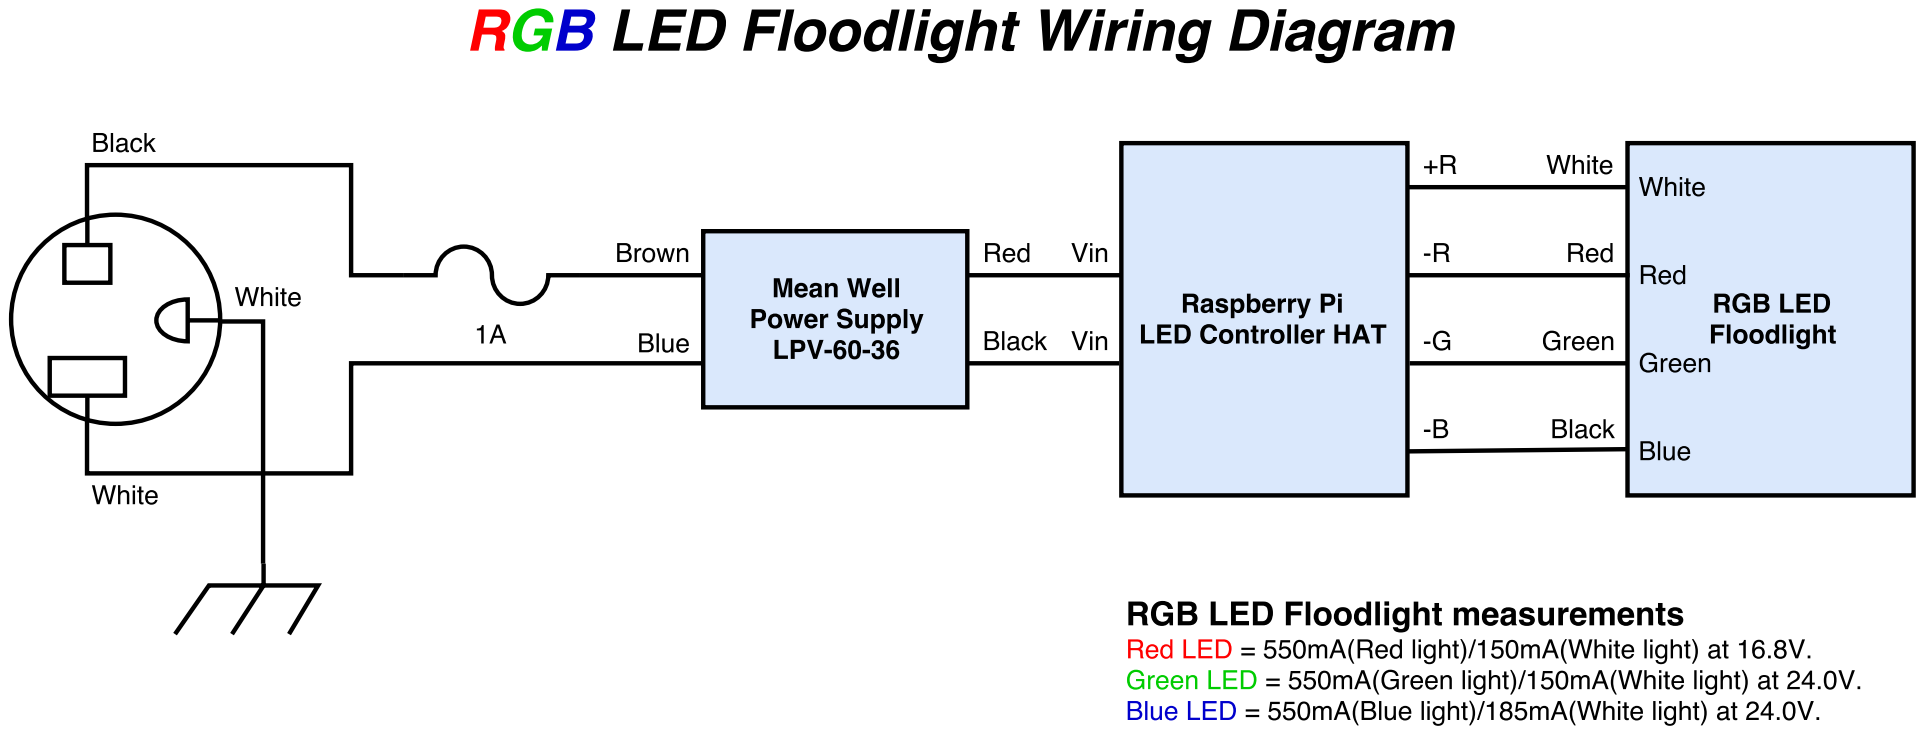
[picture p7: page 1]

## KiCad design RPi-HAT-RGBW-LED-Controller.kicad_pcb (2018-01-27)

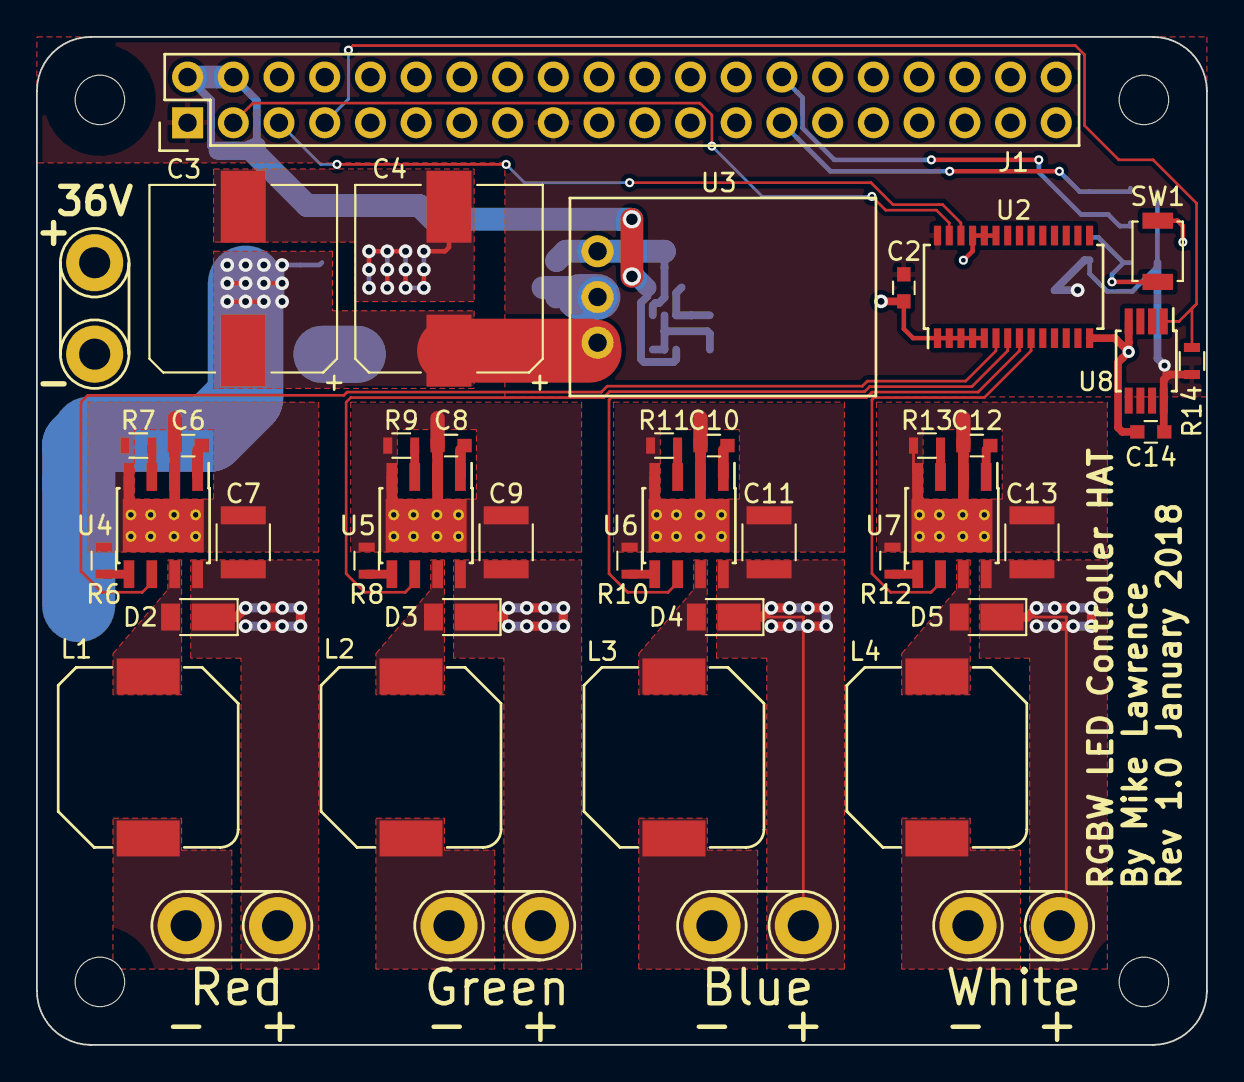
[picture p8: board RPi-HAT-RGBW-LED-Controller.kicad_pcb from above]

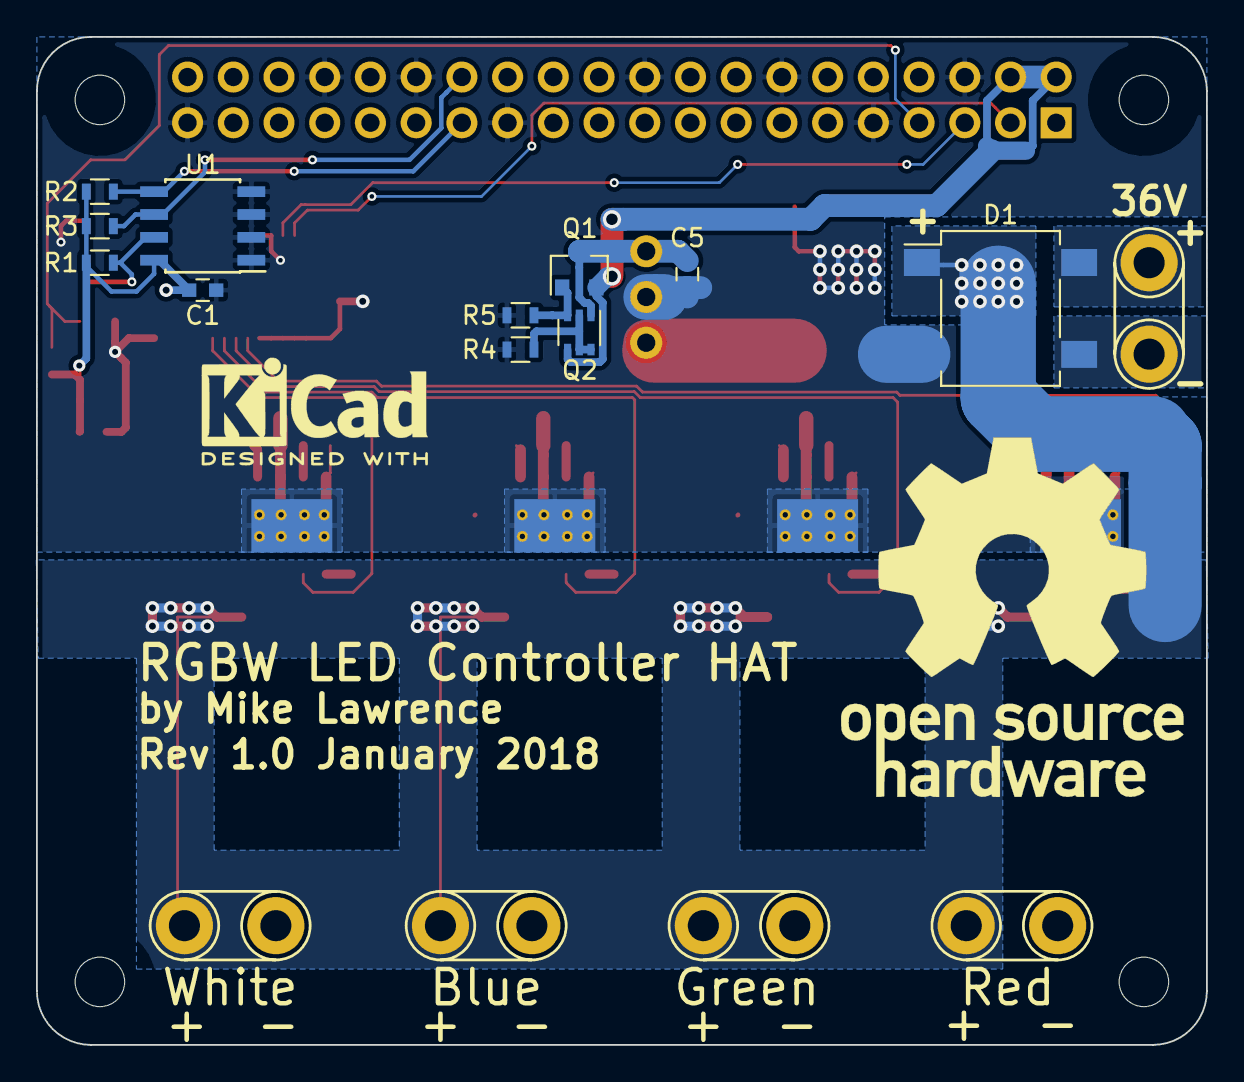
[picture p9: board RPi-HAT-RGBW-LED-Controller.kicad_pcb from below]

Board: 2 copper layers, 65.0 x 56.0 mm, 54 parts (11 on the bottom side), 39 nets.

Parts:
C1, C2, C14: 0.1uF; C_0603
C3, C4: 330uF; CP_Elec_10x10.5
C5, C6, C8, C10, C12: 1uF; C_0603
C7, C9, C11, C13: 2.2uF; C_1210
D1: D_Bridge_+-AA; Diode_Bridge_DFS
D2, D3, D4, D5: DFLS2100; D_PowerDI-123
J1: RPi_GPIO; Pin_Header_Straight_2x20
J2, J3, J4, J5, J6: Conn_01x02_Female; TH_16ga_2pos
L1, L2, L3, L4: 100uH; WE-PD-1050
Q1: DMG2305UX; SOT-23
Q2: BCM857BS; SOT-363_SC-70-6
R1: 1k; R_0603
R2, R3: 3.9k; R_0603
R4: 10k; R_0603
R5: 47k; R_0603
R6, R8, R10, R12: 40.2k; R_0603
R7, R9, R11, R13: 5.76k; R_0603
R14: 4.7k; R_0603
SW1: Write; SW_SPST_B3U-1000P
U1: AT24CS32; SOIC-8_3.9x4.9mm_Pitch1.27mm
U2: PCA9685; TSSOP-28_4.4x9.7mm_Pitch0.65mm
U3: OKI-78SR-5; 78SR-H
U4, U5, U6, U7: LM3414; TI_SO-PowerPAD-8_ThermalVias
U8: DS18B20U; MSOP-8_3x3mm_Pitch0.65mm

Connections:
+3V3: C1.1, C2.1, C14.1, J1.1, J1.17, R1.1, R2.1, R3.1, R14.1, U1.8, U2.28, U8.8
+5V: J1.2, J1.4, Q1.2, Q2.4
+5VP: C5.1, Q1.3, Q2.1, U3.3
+VDC: C3.1, C4.1, C7.1, C9.1, C11.1, C13.1, D1.1, D2.1, D3.1, D4.1, D5.1, J3.1, J4.1, J5.1, J6.1, U3.1, U4.8, U5.8, U6.8, U7.8
/-B: J5.2, L3.2
/-G: J4.2, L2.2
/-R: J3.2, L1.2
/-W: J6.2, L4.2
/ID_SC: J1.28, R3.2, U1.6
/ID_SD: J1.27, R2.2, U1.5
/LXB: D4.2, L3.1, U6.7
/LXG: D3.2, L2.1, U5.7
/LXR: D2.2, L1.1, U4.7
/LXW: D5.2, L4.1, U7.7
/SCL: J1.5, U2.26
/SDA: J1.3, U2.27
/VinA: D1.3, J2.1
/VinB: D1.4, J2.2
GND: C1.2, C2.2, C3.2, C4.2, C5.2, C6.2, C7.2, C8.2, C9.2, C10.2, C11.2, C12.2, C13.2, C14.2, D1.2, J1.6, J1.9, J1.14, J1.20, J1.25, J1.30, J1.34, J1.39, R4.2, R5.2, R6.1, R7.1, R8.1, R9.1, R10.1, R11.1, R12.1, R13.1, SW1.2, U1.1, U1.2, U1.3, U1.4, U2.1, U2.2, U2.3, U2.4, U2.5, U2.14, U2.23, U2.24, U2.25, U3.2, U4.2, U4.4, U4.9, U5.2, U5.4, U5.9, U6.2, U6.4, U6.9, U7.2, U7.4, U7.9, U8.4
unnamed: C6.1, U4.1
unnamed: C8.1, U5.1
unnamed: C10.1, U6.1
unnamed: C12.1, U7.1
unnamed: Q1.1, Q2.3, R5.1
unnamed: Q2.2, Q2.5, Q2.6, R4.1
unnamed: R1.2, SW1.1, U1.7
unnamed: R6.2, U4.5
unnamed: R7.2, U4.3
unnamed: R8.2, U5.5
unnamed: R9.2, U5.3
unnamed: R10.2, U6.5
unnamed: R11.2, U6.3
unnamed: R12.2, U7.5
unnamed: R13.2, U7.3
unnamed: U2.6, U4.6
unnamed: U2.7, U5.6
unnamed: U2.8, U6.6
unnamed: U2.9, U7.6
OW: J1.7, R14.2, U8.1

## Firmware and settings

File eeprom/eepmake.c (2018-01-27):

/*
 *    Parses EEPROM text file and createds binary .eep file
 *    Usage: eepmake input_file output_file
 */

#include <stdio.h>
#include <stdlib.h>
#include <ctype.h>
#include <string.h>
#include <stdbool.h>
#include <unistd.h>
#include <fcntl.h>

#include "eeptypes.h"

#define HEADER_SIGN 0x69502d52 //"R-Pi" in ASCII reversed for endianness

//todo: larger initial mallocs

struct header_t header;
struct atom_t *custom_atom, vinf_atom, gpio_atom, dt_atom;
struct vendor_info_d* vinf;
struct gpio_map_d* gpiomap;

bool product_serial_set, product_id_set, product_ver_set, vendor_set, product_set,
gpio_drive_set, gpio_slew_set, gpio_hysteresis_set, gpio_power_set;

bool data_receive, has_dt, receive_dt;

char **data;
char *current_atom; //rearranged to write out
unsigned int data_len, custom_ct, total_size, data_cap, custom_cap;


int write_binary(char* out) {
    FILE *fp;
    int i, offset;
    short crc;
    
    fp=fopen(out, "wb");
    if (!fp) {
        printf("Error writing file %s\n", out);
        return -1;
    }
    
    fwrite(&header, sizeof(header), 1, fp);
    
    
    current_atom = (char *) malloc(vinf_atom.dlen+ATOM_SIZE-CRC_SIZE);
    offset = 0;
    //vendor information atom first part
    memcpy(current_atom, &vinf_atom, ATOM_SIZE-CRC_SIZE);
    offset += ATOM_SIZE-2;
    //data first part
    memcpy(current_atom+offset, vinf_atom.data, VENDOR_SIZE);
    offset += VENDOR_SIZE;
    //data strings
    memcpy(current_atom+offset, vinf->vstr, vinf->vslen);
    offset += vinf->vslen;
    memcpy(current_atom+offset, vinf->pstr, vinf->pslen);
    offset += vinf->pslen;
    //vinf last part
    crc = getcrc(current_atom, offset);
    memcpy(current_atom+offset, &crc, CRC_SIZE);
    offset += CRC_SIZE;
    
    fwrite(current_atom, offset, 1, fp);
    free(current_atom);
    
    current_atom = (char *) malloc(gpio_atom.dlen+ATOM_SIZE-CRC_SIZE);
    offset = 0;
    //GPIO map first part
    memcpy(current_atom, &gpio_atom, ATOM_SIZE-CRC_SIZE);
    offset += ATOM_SIZE-CRC_SIZE;
    //GPIO data
    memcpy(current_atom+offset, gpiomap, GPIO_SIZE);
    offset += GPIO_SIZE;
    //GPIO map last part
    crc = getcrc(current_atom, offset);
    memcpy(current_atom+offset, &crc, CRC_SIZE);
    offset += CRC_SIZE;
    
    fwrite(current_atom, offset, 1, fp);
    free(current_atom);
    
    if (has_dt) {
        printf("Writing out DT...\n");
        current_atom = (char *) malloc(dt_atom.dlen+ATOM_SIZE-CRC_SIZE);
        offset = 0;
        
        memcpy(current_atom, &dt_atom, ATOM_SIZE-CRC_SIZE);
        offset += ATOM_SIZE-CRC_SIZE;
        
        memcpy(current_atom+offset, dt_atom.data, dt_atom.dlen-CRC_SIZE);
        offset += dt_atom.dlen-CRC_SIZE;
        
        crc = getcrc(current_atom, offset);
        memcpy(current_atom+offset, &crc, CRC_SIZE);
        offset += CRC_SIZE;
        
        fwrite(current_atom, offset, 1, fp);
        free(current_atom);
    }
    
    for (i = 0; i<custom_ct; i++) {
        custom_atom[i].count-=!has_dt;
        
        current_atom = (char *) malloc(custom_atom[i].dlen+ATOM_SIZE-CRC_SIZE);
        offset = 0;
        
        memcpy(current_atom, &custom_atom[i], ATOM_SIZE-CRC_SIZE);
        offset += ATOM_SIZE-CRC_SIZE;
        
        memcpy(current_atom+offset, custom_atom[i].data, custom_atom[i].dlen-CRC_SIZE);
        offset += custom_atom[i].dlen-CRC_SIZE;
        
        crc = getcrc(current_atom, offset);
        memcpy(current_atom+offset, &crc, CRC_SIZE);
        offset += CRC_SIZE;
        
        fwrite(current_atom, offset, 1, fp);
        free(current_atom);
    }
    
    
    fflush(fp);
    fclose(fp);
    return 0;
}


void parse_data(char* c) {
    int k;
    char s;
    char* i = c;
    char* j = c;
    while(*j != '\0')
    {
        *i = *j++;
        if(isxdigit(*i))
            i++;
    }
    *i = '\0';
    
    int len = strlen(c);
    if (len % 2 != 0) {
        printf("Error: data must have an even number of hex digits\n");
    } else {
        for (k = 0; k<len/2; k++) {
            //read a byte at a time
            s = *(c+2);
            *(c+2)='\0';
            
            if (data_len==data_cap) {
                data_cap *=2;
                *data = (char *) realloc(*data, data_cap);
            }
            
            sscanf(c, "%2x", *data+data_len++);
            
            *(c+2) = s;
            c+=2;
        }
    }
}


void finish_data() {
    if (data_receive) {
        *data = (char *) realloc(*data, data_len);
        
        total_size+=ATOM_SIZE+data_len;
        
        if (receive_dt) {
            dt_atom.type = ATOM_DT_TYPE;
            dt_atom.count = ATOM_DT_NUM;
            dt_atom.dlen = data_len+CRC_SIZE;
        } else {
            //finish atom description
            custom_atom[custom_ct].type = ATOM_CUSTOM_TYPE;
            custom_atom[custom_ct].count = 3+custom_ct;
            custom_atom[custom_ct].dlen = data_len+CRC_SIZE;
            
            custom_ct++;
        }
    }
}


void parse_command(char* cmd, char* c) {
    int val;
    uint32_t high1, high2;
    char *fn, *pull;
    char pin;
    bool valid;
    bool continue_data=false;
    
    /* Vendor info related part */
    if (strcmp(cmd, "product_uuid")==0) {
        product_serial_set = true; //required field
        high1 = 0; high2 = 0;
        
        sscanf(c, "%100s %08x-%04x-%04x-%04x-%04x%08x\n", cmd, &vinf->serial_4,
               &high1, &vinf->serial_3, &high2, &vinf->serial_2, &vinf->serial_1);
        
        vinf->serial_3 |= high1<<16;
        vinf->serial_2 |= high2<<16;
        
        if ((vinf->serial_4==0) && (vinf->serial_3==0) && (vinf->serial_2==0) && (vinf->serial_1==0)) {
            //read 128 random bits from /dev/urandom
            int random_file = open("/dev/urandom", O_RDONLY);
            ssize_t result = read(random_file, &vinf->serial_1, 16);
            close(random_file);
            if (result <= 0) printf("Unable to read from /dev/urandom to set up UUID");
            else {
                //put in the version
                vinf->serial_3 = (vinf->serial_3 & 0xffff0fff) | 0x00004000;
                
                //put in the variant
                vinf->serial_2 = (vinf->serial_2 & 0x3fffffff) | 0x80000000;
                
                printf("UUID=%08x-%04x-%04x-%04x-%04x%08x\n", vinf->serial_4, vinf->serial_3>>16, vinf->serial_3 & 0xffff, vinf->serial_2>>16, vinf->serial_2 & 0xffff, vinf->serial_1);
            }
            
        }
        
    } else if (strcmp(cmd, "product_id")==0) {
        product_id_set = true; //required field
        sscanf(c, "%100s %hx", cmd, &vinf->pid);
        
    } else if (strcmp(cmd, "product_ver")==0) {
        product_ver_set = true; //required field
        sscanf(c, "%100s %hx", cmd, &vinf->pver);
        
    } else if (strcmp(cmd, "vendor")==0) {
        vendor_set = true; //required field
        
        vinf->vstr = (char*) malloc (256);
        sscanf(c, "%100s \"%255[^\"]\"", cmd, vinf->vstr);
        
        total_size-=vinf->vslen;
        vinf_atom.dlen-=vinf->vslen;
        
        vinf->vslen = strlen(vinf->vstr);
        
        total_size+=vinf->vslen;
        vinf_atom.dlen+=vinf->vslen;
        
    } else if (strcmp(cmd, "product")==0) {
        product_set = true; //required field
        
        vinf->pstr = (char*) malloc (256);
        sscanf(c, "%100s \"%255[^\"]\"", cmd, vinf->pstr);
        
        total_size-=vinf->pslen;
        vinf_atom.dlen-=vinf->pslen;
        
        vinf->pslen = strlen(vinf->pstr);
        
        total_size+=vinf->pslen;
        vinf_atom.dlen+=vinf->pslen;
    }
    
    /* GPIO map related part */
    else if (strcmp(cmd, "gpio_drive")==0) {
        gpio_drive_set = true; //required field
        
        sscanf(c, "%100s %1x", cmd, &val);
        if (val>8 || val<0) printf("Warning: gpio_drive property in invalid region, using default value instead\n");
        else gpiomap->flags |= val;
        
        
    } else if (strcmp(cmd, "gpio_slew")==0) {
        gpio_slew_set = true; //required field
        
        sscanf(c, "%100s %1x", cmd, &val);
        
        if (val>2 || val<0) printf("Warning: gpio_slew property in invalid region, using default value instead\n");
        else gpiomap->flags |= val<<4;
        
    } else if (strcmp(cmd, "gpio_hysteresis")==0) {
        gpio_hysteresis_set = true; //required field
        
        sscanf(c, "%100s %1x", cmd, &val);
        
        if (val>2 || val<0) printf("Warning: gpio_hysteresis property in invalid region, using default value instead\n");
        else gpiomap->flags |= val<<6;
        
    } else if (strcmp(cmd, "back_power")==0) {
        gpio_power_set = true; //required field
        
        sscanf(c, "%100s %1x", cmd, &val);
        
        if (val>2 || val<0) printf("Warning: back_power property in invalid region, using default value instead\n");
        else gpiomap->power = val;
        
    } else if (strcmp(cmd, "setgpio")==0) {
        fn = (char*) malloc (101);
        pull = (char*) malloc (101);
        
        sscanf(c, "%100s %d %100s %100s", cmd, &val, fn, pull);
        
        if (val<GPIO_MIN || val>=GPIO_COUNT) printf("Error: GPIO number out of bounds\n");
        else {
            valid = true;
            pin = 0;
            
            if (strcmp(fn, "INPUT")==0) {
                //no action
            } else if (strcmp(fn, "OUTPUT")==0) {
                pin |= 1;
            } else if (strcmp(fn, "ALT0")==0) {
                pin |= 4;
            } else if (strcmp(fn, "ALT1")==0) {
                pin |= 5;
            } else if (strcmp(fn, "ALT2")==0) {
                pin |= 6;
            } else if (strcmp(fn, "ALT3")==0) {
                pin |= 7;
            } else if (strcmp(fn, "ALT4")==0) {
                pin |= 3;
            } else if (strcmp(fn, "ALT5")==0) {
                pin |= 2;
            } else {
                printf("Error at setgpio: function type not recognised\n");
                valid=false;
            }
            
            if (strcmp(pull, "DEFAULT")==0) {
                //no action
            } else if (strcmp(pull, "UP")==0) {
                pin |= 1<<5;
            } else if (strcmp(pull, "DOWN")==0) {
                pin |= 2<<5;
            } else if (strcmp(pull, "NONE")==0) {
                pin |= 3<<5;
            } else {
                printf("Error at setgpio: pull type not recognised\n");
                valid=false;
            }
            
            pin |= 1<<7; //board uses this pin
            
            if (valid) gpiomap->pins[val] = pin;
        }
    }
    
    /* DT atom related part */
    else if (strcmp(cmd, "dt_blob")==0) {
        finish_data();
        
        has_dt = true;
        c+=strlen("dt_blob");
        
        receive_dt=true;
        data_receive=true;
        
        data_len = 0;
        data_cap = 4;
        data = &dt_atom.data;
        *data = (char *) malloc(data_cap);
        
        parse_data(c);
        continue_data = true;
        
    }
    
    /* Custom data related part */
    else if (strcmp(cmd, "custom_data")==0) {
        finish_data();
        
        c+=strlen("custom_data");
        
        if (custom_cap == custom_ct) {
            custom_cap *= 2;
            custom_atom = (struct atom_t*) realloc(custom_atom, custom_cap * sizeof(struct atom_t));
        }
        
        receive_dt=false;
        data_receive=true;
        
        data_len = 0;
        data_cap = 4;
        data = &custom_atom[custom_ct].data;
        *data = (char *) malloc(data_cap);
        
        parse_data(c);
        continue_data = true;
        
    } else if (strcmp(cmd, "end") ==0) {
        //close last data atom
        continue_data=false;
    }
    /* Incoming data */
    else if (data_receive) {
        parse_data(c);
        continue_data = true;
    }
    
    
    if (!continue_data) finish_data();
    
}

int read_text(char* in) {
    FILE * fp;
    char * line = NULL;
    char * c = NULL;
    size_t len = 0;
    ssize_t read;
    char *comment = NULL;
    int atomct = 2;
    int linect = 0;
    char * command = (char*) malloc (101);
    int i;
    
    has_dt = false;
    
    printf("Opening file %s for read\n", in);
    
    fp = fopen(in, "r");
    if (fp == NULL) {
        printf("Error opening input file\n");
        return -1;
    }
    
    //allocating memory and setting up required atoms
    custom_cap = 1;
    custom_atom = (struct atom_t*) malloc(sizeof(struct atom_t) * custom_cap);
    
    total_size=ATOM_SIZE*2+HEADER_SIZE+VENDOR_SIZE+GPIO_SIZE;
    
    vinf_atom.type = ATOM_VENDOR_TYPE;
    vinf_atom.count = ATOM_VENDOR_NUM;
    vinf = (struct vendor_info_d *) malloc(sizeof(struct vendor_info_d));
    vinf_atom.data = (char *)vinf;
    vinf_atom.dlen = VENDOR_SIZE + CRC_SIZE;
    
    gpio_atom.type = ATOM_GPIO_TYPE;
    gpio_atom.count = ATOM_GPIO_NUM;
    gpiomap = (struct gpio_map_d *) malloc(sizeof(struct gpio_map_d));
    gpio_atom.data = (char *)gpiomap;
    gpio_atom.dlen = GPIO_SIZE + CRC_SIZE;
    
    while ((read = getline(&line, &len, fp)) != -1) {
        linect++;
        c = line;
        
        for (i=0; i<read; i++) if (c[i]=='#') c[i]='\0';
        
        while (isspace(*c)) ++c;
        
        
        if (*c=='\0' || *c=='\n' || *c=='\r') {
            //empty line, do nothing
        } else if (isalnum (*c)) {
            sscanf(c, "%100s", command);
            
#ifdef DEBUG
            printf("Processing line %u: %s", linect, c);
            if ((*(c+strlen(c)-1))!='\n') printf("\n");
#endif
            
            parse_command(command, c);
            
            
        } else printf("Can't parse line %u: %s", linect, c);
    }
    
    finish_data();
    
    if (!product_serial_set || !product_id_set || !product_ver_set || !vendor_set || !product_set ||
        !gpio_drive_set || !gpio_slew_set || !gpio_hysteresis_set || !gpio_power_set) {
        
        printf("Warning: required fields missing in vendor information or GPIO map, using default values\n");
    }
    
    printf("Done reading\n");
    
    return 0;
}


int read_dt(char* in) {
    FILE * fp;
    unsigned long size = 0;
    
    printf("Opening DT file %s for read\n", in);
    
    fp = fopen(in, "r");
    if (fp == NULL) {
        printf("Error opening input file\n");
        return -1;
    }
    
    fseek(fp, 0L, SEEK_END);
    size = ftell(fp);
    fseek(fp, 0L, SEEK_SET);
    
    printf("Adding %lu bytes of DT data\n", size);
    
    total_size+=ATOM_SIZE+size;
    has_dt = true;
    dt_atom.type = ATOM_DT_TYPE;
    dt_atom.count = ATOM_DT_NUM;
    dt_atom.dlen = size+CRC_SIZE;
    
    dt_atom.data = (char *) malloc(size);
    if (!fread(dt_atom.data, size, 1, fp)) goto err;
    
    
    fclose(fp);
    return 0;
    
err:
    printf("Unexpected EOF or error occurred\n");
    fclose(fp);
    return 0;
    
}

int read_custom(char* in) {
    FILE * fp;
    unsigned long size = 0;
    
    printf("Opening custom data file %s for read\n", in);
    
    fp = fopen(in, "r");
    if (fp == NULL) {
        printf("Error opening input file\n");
        return -1;
    }
    
    fseek(fp, 0L, SEEK_END);
    size = ftell(fp);
    fseek(fp, 0L, SEEK_SET);
    
    printf("Adding %lu bytes of custom data\n", size);
    
    total_size+=ATOM_SIZE+size;
    
    custom_atom[custom_ct].type = ATOM_CUSTOM_TYPE;
    custom_atom[custom_ct].count = 3+custom_ct;
    custom_atom[custom_ct].dlen = size+CRC_SIZE;
    
    custom_atom[custom_ct].data = (char *) malloc(size);
    if (!fread(custom_atom[custom_ct].data, size, 1, fp)) goto err;
    
    custom_ct++;
    
    fclose(fp);
    return 0;
    
err:
    printf("Unexpected EOF or error occurred\n");
    fclose(fp);
    return 0;
    
}
int main(int argc, char *argv[]) {
    int ret;
    int i, custom_o=0;
    
    if (argc<3) {
        printf("Wrong input format.\n");
        printf("Try 'eepmake input_file output_file [dt_file] [-c custom_file_1 ... custom_file_n]'\n");
        return 0;
    }
    
    
    ret = read_text(argv[1]);
    if (ret) {
        printf("Error reading and parsing input, aborting\n");
        return 0;
    }
    
    if (argc>3) {
        if (strcmp(argv[3], "-c")==0) {
            custom_o=4;
        } else {
            //DT file specified
            if (dt_atom.dlen) total_size-=(ATOM_SIZE +dt_atom.dlen - CRC_SIZE);
            ret = read_dt(argv[3]);
            if (ret) {
                printf("Error reading DT file, aborting\n");
                return 0;
            }
        }
    }
    
    if (argc>4 && strcmp(argv[4], "-c")==0) custom_o = 5;
    
    if (custom_o)
        for (i = custom_o; i<argc; i++) {
            //new custom data file
            ret = read_custom(argv[i]);
            if (ret) {
                printf("Error reading DT file, aborting\n");
                return 0;
            }
        }
    
    header.signature = HEADER_SIGN;
    header.ver = FORMAT_VERSION;
    header.res = 0;
    header.numatoms = 2+has_dt+custom_ct;
    header.eeplen = total_size;
    
    printf("Writing out...\n");
    
    ret = write_binary(argv[2]);
    if (ret) {
        printf("Error writing output\n");
        return 0;
    }
    
    printf("Done.\n");
    
    return 0;
}

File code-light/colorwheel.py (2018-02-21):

# -*- coding: UTF-8 -*-
#
# Copyright (c) 2018 Mike Lawrence
#
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
from color import Color
import color
import math
import logging

# logger for this module
logger = logging.getLogger(__name__)

WheelList = ['Single Color', 'Single Color Bounce', 'Primary Bounce',
             'Primary Blend', 'Rainbow Bounce', 'Rainbow Blend', 'Christmas',
             'Halloween']

def getcolorwheellist():
    """Gets a list of color wheel names."""
    return WheelList

def getcolorwheelfromname(name, color):
    """Gets an initialized ColorWheel from name and color."""
    if name not in WheelList:
        raise ValueError("Name is not a valid ColorWheel")

    if name == WheelList[0]:
        # Single Color
        return ColorBlendWheel([color])
    if name == WheelList[1]:
        # Single Color Bounce
        return ColorBounceWheel([color, color])
    if name == WheelList[2]:
        # Primary Bounce
        return PrimaryBounceWheel()
    if name == WheelList[3]:
        # Primary Blend
        return PrimaryBlendWheel()
    if name == WheelList[4]:
        # Rainbow Bounce
        return RainbowBounceWheel()
    if name == WheelList[5]:
        # Rainbow Blend
        return RainbowBlendWheel()
    if name == WheelList[6]:
        # Christmas
        return ChristmasBounceWheel()
    if name == WheelList[7]:
        # Halloween
        return HalloweenBounceWheel()

class ColorWheel:
    """Base class for Color Wheel. Cannot be used directly. """
    def getrgb(self, angle):
        """
        Method stub for getting an RGB color from an angle.

        Has to be implemented by inheriting classes.
        :param hue: Angle range 0 - 360.

        :return: Returns RGB color for specified angle.
        """
        raise NotImplementedError


class PrimarySineWheel(ColorWheel):
    def getrgb(self, angle):
        """
        Get sine wave RGB color from an angle.

        :param hue: Angle range 0 - 360.

        :return: Returns RGB color for specified angle.
        """
        # force angle into range
        value = angle % 360
        if value < 0:
            value += 360
        scale = 255 / 2

        # get colors based on value, red first
        if value < 120:
            red = round((math.cos(math.radians(value * 1.5)) + 1) * scale)
        elif value >= 240:
            red = round((1 - math.cos(math.radians((value - 240) * 1.5)))
                        * scale)
        else:
            red = 0
        # handle green
        if value < 240:
            green = round((1 - math.cos(math.radians(value * 1.5))) * scale)
        else:
            green = 0
        # handle blue
        if value < 120:
            blue = 0
        else:
            blue = round((1 - math.cos(math.radians((value - 120) * 1.5)))
                         * scale)

        return Color(red, green, blue)


class ColorBlendWheel(ColorWheel):
    """Color Wheel that will blend between colors in a list."""
    def __init__(self, colors):
        # Save list of colors. It is expected that the first and last
        # colors are the same
        self._colors = colors

    def getrgb(self, angle):
        """
        Get a blend RGB color from a set of colors using an angle.

        :param angle: Angle range 0 - 360.

        :return: Returns RGB color for specified angle.
        """
        # if there is only one color then return it
        if len(self._colors) == 1:
            return self._colors[0]

        # force angle into range
        value = angle % 360
        if value < 0:
            value += 360

        # determine section values from number of colors
        sectionDegrees = 360 / (len(self._colors) - 1)
        sectionCurrent = int(value / sectionDegrees)
        sectionValue = value - sectionCurrent * sectionDegrees
        sectionBias = sectionValue / sectionDegrees
        fromColor = self._colors[sectionCurrent]
        toColor = self._colors[sectionCurrent + 1]
        # get RGB color
        color = fromColor.blend(toColor, sectionBias)
        #print("∠=%.2f S∠=%.2f S=%d Bias=%.2f C=(%s)" % (value, sectionValue,
        #      sectionCurrent, sectionBias, color))
        return(color)


class PrimaryBlendWheel(ColorBlendWheel):
    """Color Wheel that will blend between primary colors."""
    def __init__(self):
        super().__init__(Color.Primary)


class RainbowBlendWheel(ColorBlendWheel):
    """Color Wheel that will blend between rainbow colors."""
    def __init__(self):
        super().__init__(Color.Rainbow)


class ChristmasBlendWheel(ColorBlendWheel):
    """Color Wheel that will blend between Christmas colors."""
    def __init__(self):
        super().__init__(Color.Christmas)


class HalloweenBlendWheel(ColorBlendWheel):
    """Color Wheel that will blend between Halloween colors."""
    def __init__(self):
        super().__init__(Color.Halloween)


class ColorBounceWheel(ColorWheel):
    """Color Wheel that will beat intensity between colors in a list."""
    def __init__(self, colors):
        # Save list of colors. It is expected that the first and last
        # colors are the same
        self._colors = colors

    def getrgb(self, angle):
        """
        Get a beat RGB color from a set of colors using an angle.

        :param angle: Angle range 0 - 360.

        :return: Returns RGB color for specified angle.
        """
        # force angle into range
        value = angle % 360
        if value < 0:
            value += 360

        # determine section values from number of colors
        sectionDegrees = 360 / (len(self._colors) - 1)
        sectionValue = value + sectionDegrees / 2
        sectionCurrent = int(sectionValue / sectionDegrees)
        color = self._colors[sectionCurrent]
        # get intensity based on angle
        intensity = math.fabs(
            math.cos(math.radians(value * (len(self._colors) - 1) / 2)))
        # correct color selected now adjust color intensity
        red = color.r * intensity
        green = color.g * intensity
        blue = color.b * intensity
        color = Color(red, green, blue)
        #print("∠=%.2f S∠=%.2f S=%d I=%.2f C=(%s)" % (value, sectionValue,
        #      sectionCurrent, intensity, color))
        return(color)


class PrimaryBounceWheel(ColorBounceWheel):
    """Color Wheel that will beat intensity between primary colors."""
    def __init__(self):
        super().__init__(Color.Primary)


class RainbowBounceWheel(ColorBounceWheel):
    """Color Wheel that will beat intensity between rainbow colors."""
    def __init__(self):
        super().__init__(Color.Rainbow)


class ChristmasBounceWheel(ColorBounceWheel):
    """Color Wheel that will beat intensity between Christmas colors."""
    def __init__(self):
        super().__init__(Color.Christmas)


class HalloweenBounceWheel(ColorBounceWheel):
    """Color Wheel that will beat intensity between Halloween colors."""
    def __init__(self):
        super().__init__(Color.Halloween)

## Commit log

2018-01-27 Fix Board Preview
2018-05-31 Fix max temperature algorithm. Fixed mistake in Home Assistant yaml configuration in README.
    [rgbfloodlight.py]
2018-06-03 Added RSSI sensor to MQTT. Handle initial MQTT connect better.
    MQTT connect now looks for exceptions and will retry forever until connected. Replaces dashes in Node_ID and Group_ID with underscores. Home Assistant automatically replaces dashes and other special characters with an underscore. Now configuration file matches entity_id in Home Assistant.
    [rgbfloodlight.py]
2018-07-24 Upgrade to KiCad 5.0.0. Remove necessary files.
2019-06-28 Added MQTT authentication and improved availability for Home Assistant.
    Added MQTT username and password authentication.
    Better support for Home Assistant availabilty.
    Changed to Home Assistant MQTT discovery abbreviations.
    MQTT QOS is now defined in one place.
    Fix configuration defaults in configparser.
    [rgbfloodlight.py]
2021-11-08 Update Kicad link.
